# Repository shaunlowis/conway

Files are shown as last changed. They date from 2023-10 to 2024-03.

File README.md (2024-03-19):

# conway
Using my own implementation of Conway's game of life to learn more about embedded software.

# Notes to the weary traveler
- If you want to repeat this project, first order your cherry MX keys, then check the PCB layout.
  For me, the connector pins were on different locations than the schematic file I got. Update this afterwards.
- It is extremely unlikely that your LCD will have the same pinouts as mine, double check this part.
- My LCD's pins aren't in the middle of the PCB (Check the final image), if you care about this, you might want
  to adjust the location of the pins so the buttons are neatly aligned under the screen.

## Goal/Overview

- The PCB itself is supposed to just be a nice bit of desk decoration. It can all be powered
from a USB cable, connected to the STM. 
- Started out with a basic design to perpetually render Conway's game of life on an LCD
screen. Naturally scope creep ensued:
    - Made a custom PCB for mounting the screen and connecting to it.
    - Added buttons and LEDs for different rules to use.
    - Figured keyboard keys would work quite well for this. Updated PCB accordingly
- Wound up with a relatively useful shield that can be repurposed for future projects.

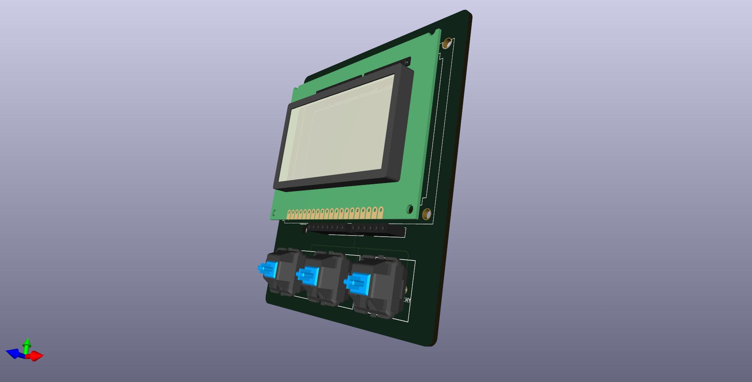
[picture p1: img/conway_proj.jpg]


First version:
<details>
<summary> Initial breadboard layout</summary>

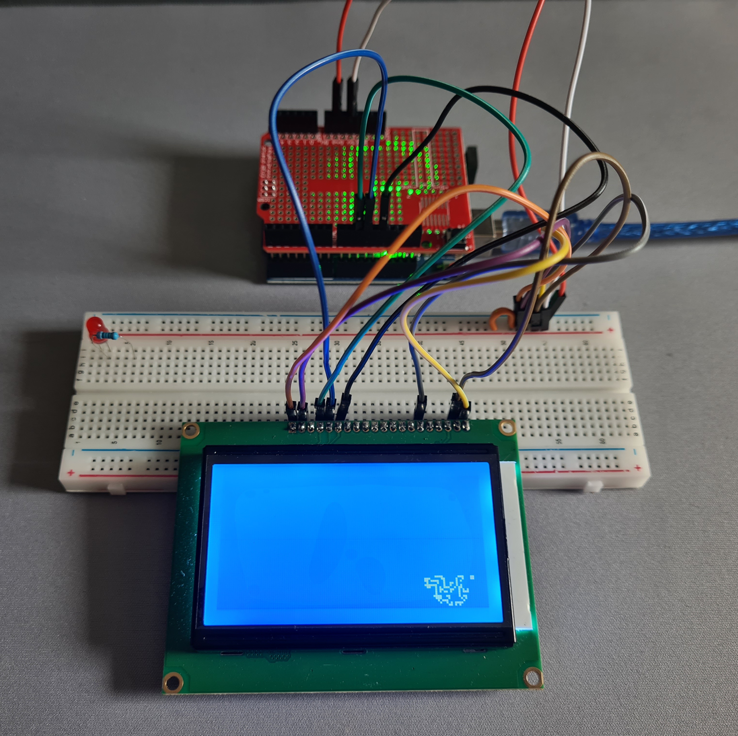
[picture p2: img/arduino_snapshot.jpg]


</details>

### Arduino support
The standard Arduino Uno does not have enough on-board memory to support a 128x64 pixel display.
In my case, pictured above, I wanted to release a version of this code that works easily for the average user.
Hence reducing the screen size to 64x36 is the largest section that we can run with a simple approach to Conway's game of life.

### Python demo
The software for Conway's game of life, for a basic python version and Arduino can be found in `/software`.

### LCD Screen config
The U8G2 Arduino library has a large amount of support for LCD screens, available [here](https://github.com/olikraus/u8g2/wiki/u8g2setupcpp). I used the `ST7920_128X64` module.

Refer to the LCD datasheet in `/circuitry` for wiring.

### STM Nucleo
On an STM32 NULCEO-F411RE, with more memory, the full 128x64 LCD screen is easily rendered.
I have made a shield that the screen can connect to directly using kicad 7. 
These files can be found under `/circuitry/kicad`. 

Install the Arduino library, then STM Core library from [here](https://github.com/stm32duino/Arduino_Core_STM32).

Great documentation on installing STM support [here](https://github.com/stm32duino/Arduino_Core_STM32/wiki/Getting-Started).

Summary of above STM install:

Install the STM Cube programmer software (required), from [here](https://www.st.com/en/development-tools/stm32cubeprog.html#get-software).
You will need to check your email for the download link to the above.

You can go to File -> Preferences -> Additional boards manager URLs, paste the link in the above documentation here.

Then click the Boards Manager icon, type "STM", then install "STM32 MCU based boards".

We can now go to "Select Board" --> Easiest to connect the STM to your PC and check its name. For me, I selected Nucleo-64.

Make sure you additionally select the correct board part number! This caught me out initially. This is in the "Tools" drop-down menu.
You can plug in your STM to your PC and open the `MBED` file, which opens a webpage with details on the model number and so-on.
If you don't have network access, your board should show up with the part number as its name as a drive in your PC.

Finally, the code uses the U8g2lib, which can be installed with: Library Manager --> search "U8g2", install first result.

<details>
<summary> First, basic layout</summary>

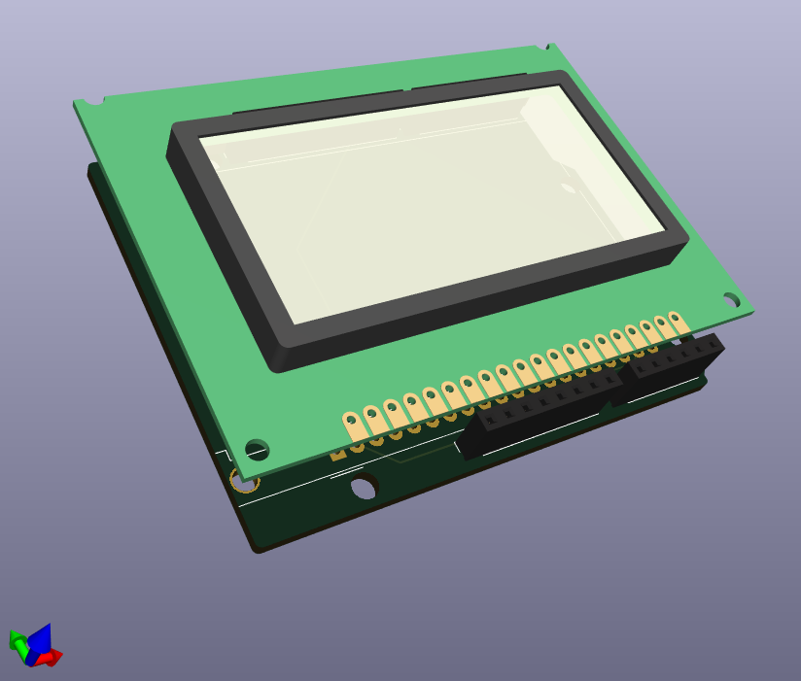
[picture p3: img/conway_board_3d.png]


Example wiring.
Barebones only display updating is in `conway_stm64.ino` for full display and a counter of generations.

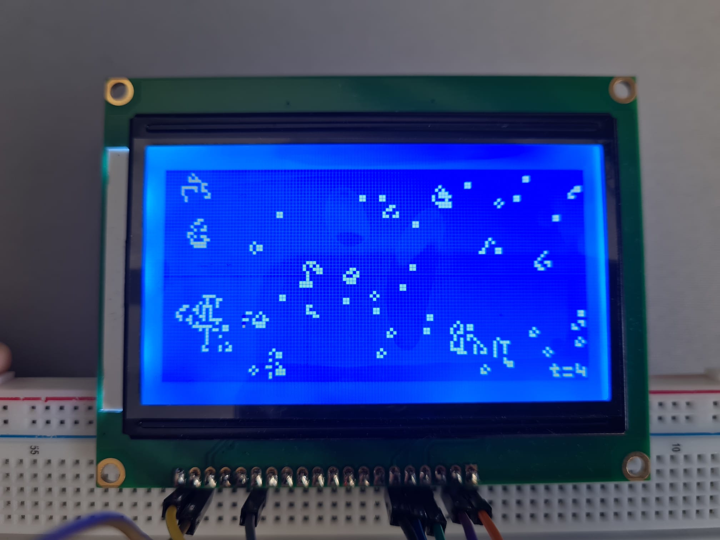
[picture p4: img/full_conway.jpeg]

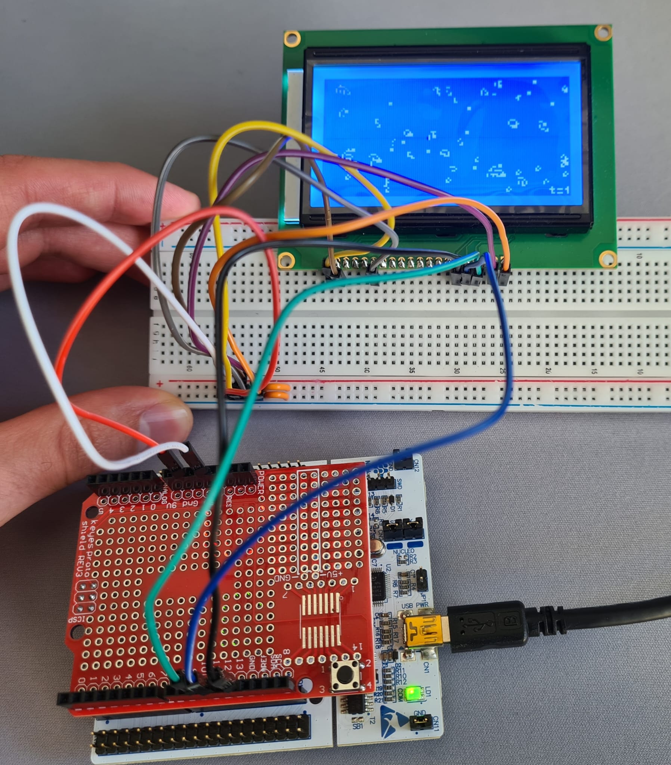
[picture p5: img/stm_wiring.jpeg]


</details>

#### Adding buttons

Additionally, buttons and LEDs were added so the user can choose different rulesets to use
for Conway's game of life. Pictured below is the "white" LED shining from selecting the
Morley's miracle rules, by clicking the white button.

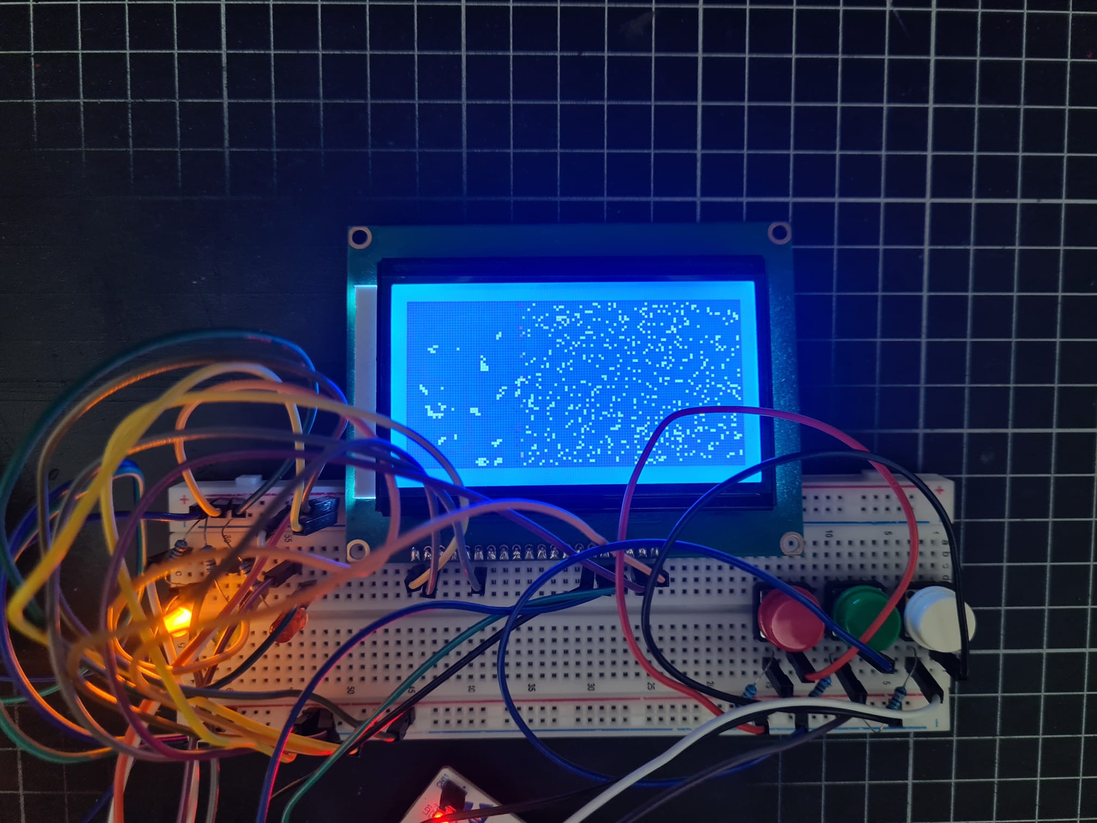
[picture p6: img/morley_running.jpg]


We now also have a more elegant PCB with support for Cherry MX keys:
I found [these](https://www.digikey.co.nz/en/products/detail/cherry-americas-llc/MX1A-E1NW/20180) 
on Digikey that had nice 3D files. This yielded the screenshot in the Overview section.

## Final PCB with screen:

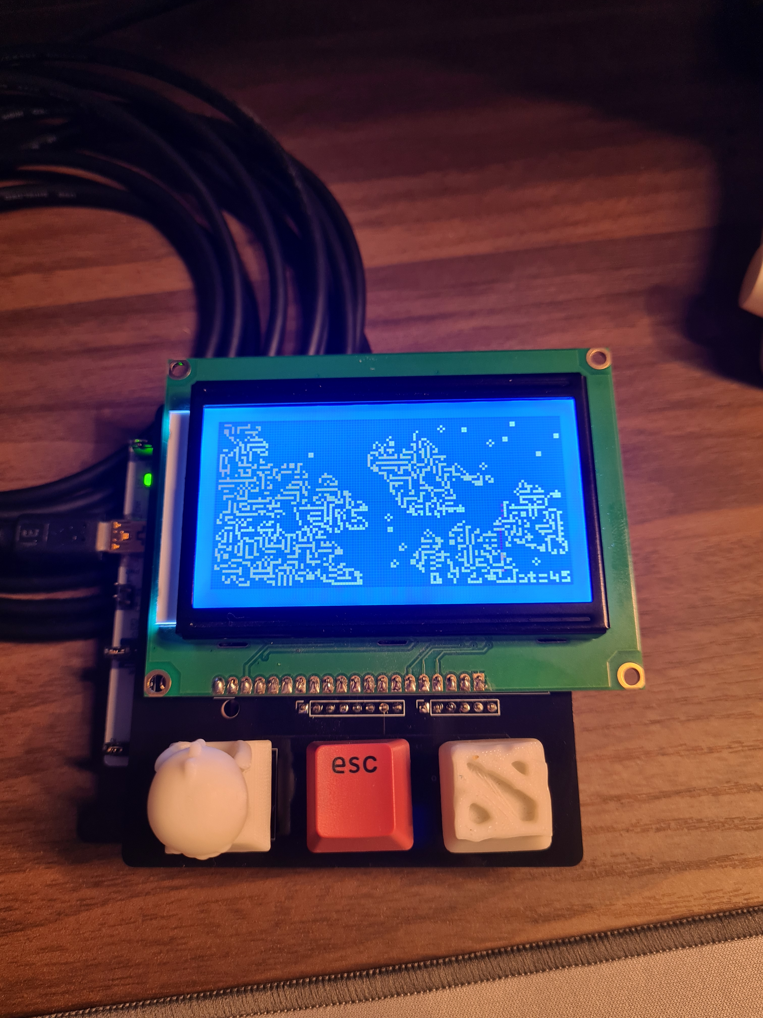
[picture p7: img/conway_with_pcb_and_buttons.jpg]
Funcitonal PCB


### TODO:
Hardware:
- Make a 3D-printed case for this, done on onshape, the .stl will be added in `/enclosure`.
- Keycaps are stupdidly expensive on Digikey, at $9 each. I should 3D print some, will also add to above folder.

Software:
- Add support for the cherry keys as they don't have resistors. See [here](https://docs.arduino.cc/tutorials/generic/digital-input-pullup/).
- Add in a button press combination to restart the simulation.
- Weird bug where pulling the power on the card fills the screen with chinese characters? Doing a reset loads graphics properly.
      - Honestly this is pretty funny so might not try to diagnose.

Reference file structure:
```
.
├── circuitry
├── enclosure
├── img
└── software
```

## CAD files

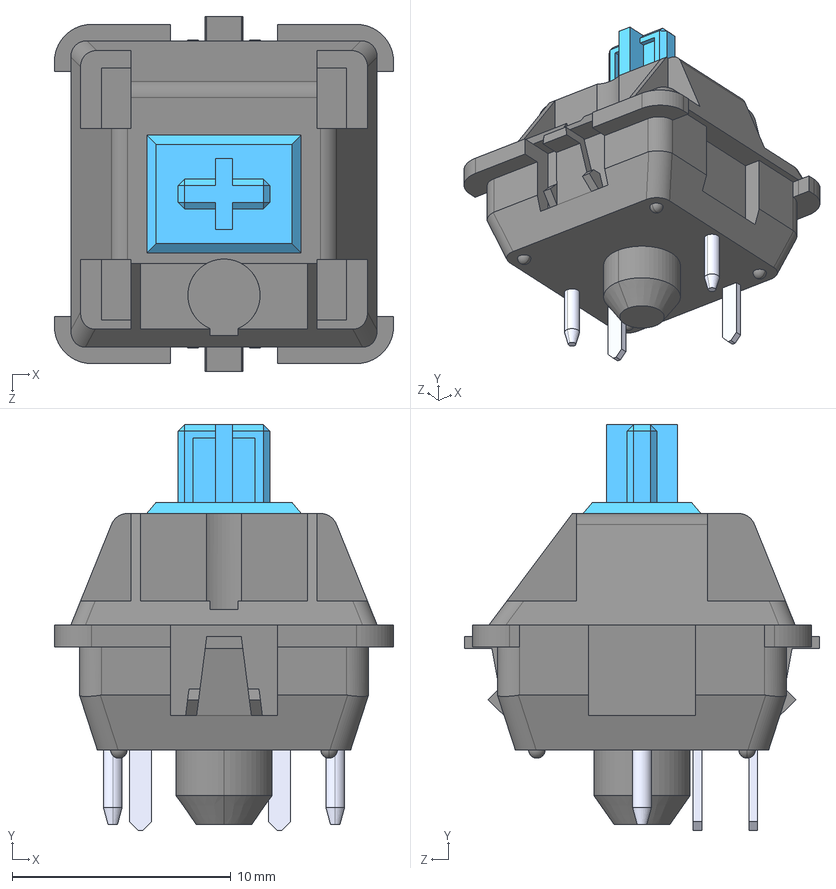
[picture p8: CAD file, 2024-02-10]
circuitry/kicad/MX1A_E1NW/KiCAD/MX1A-E1NW.STEP
15.5 x 18.5 x 16.2 mm

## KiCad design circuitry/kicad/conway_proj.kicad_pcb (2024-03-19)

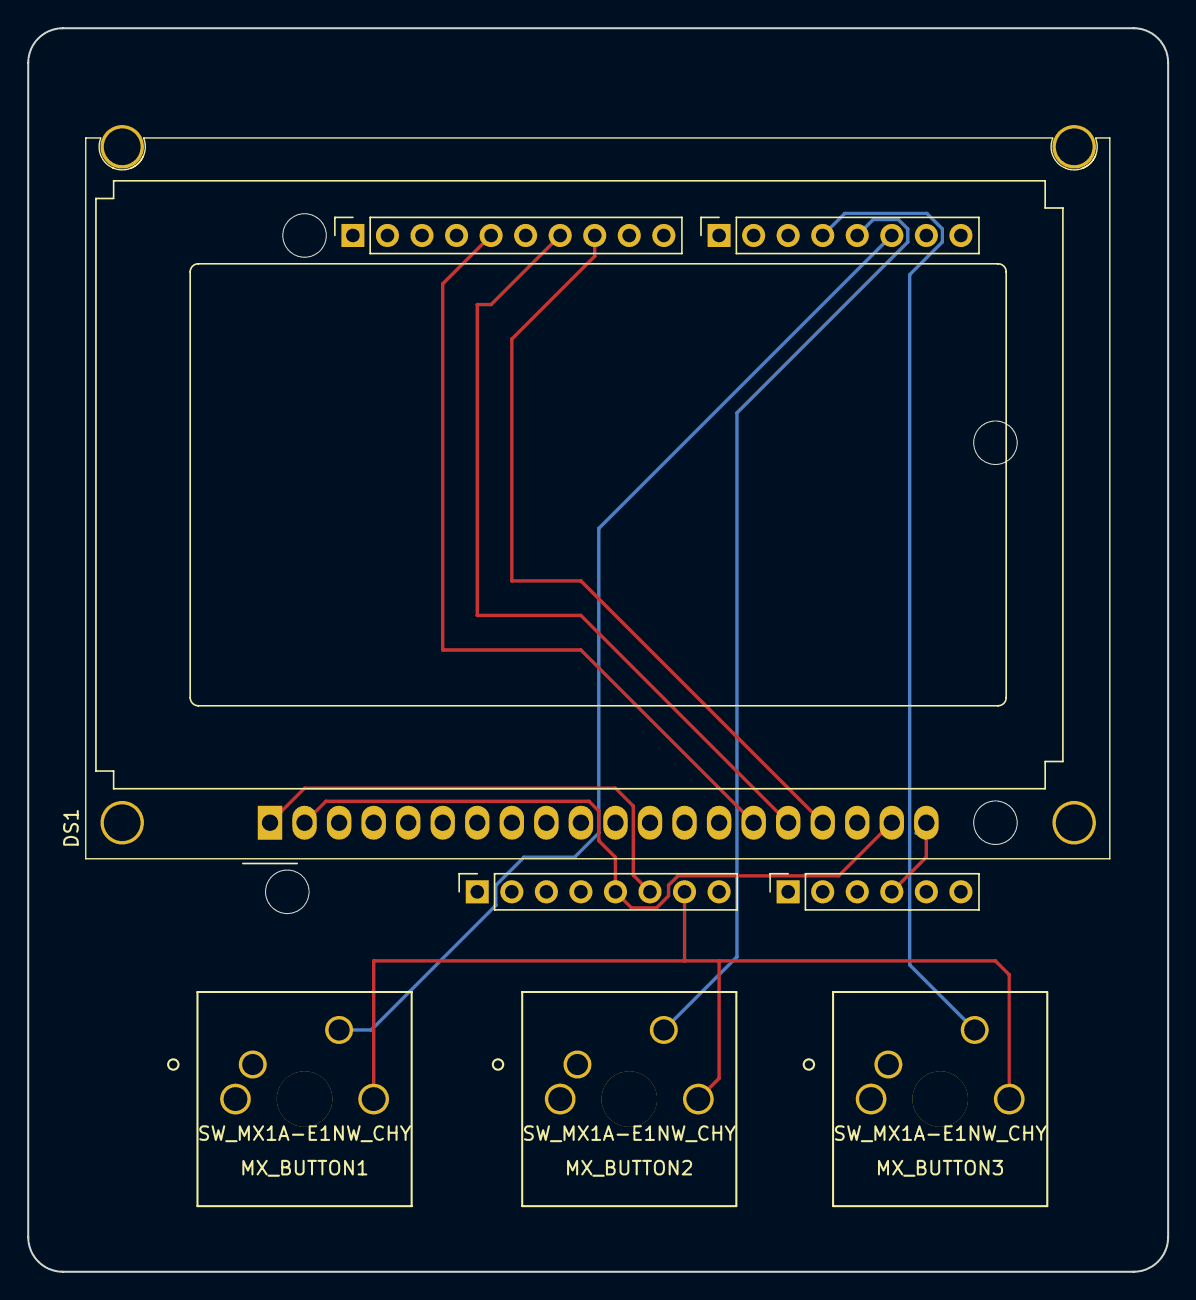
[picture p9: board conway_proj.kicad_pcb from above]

Board: 2 copper layers, 83.8 x 91.4 mm, 12 parts (0 on the bottom side), 11 nets.

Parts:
DS1: ST7920; AG12864E
J1: Power; PinSocket_1x08_P2.54mm_Vertical
J2: Digital/PWM; PinSocket_1x10_P2.54mm_Vertical
J3: Analog; PinSocket_1x06_P2.54mm_Vertical
J4: Digital/PWM; PinSocket_1x08_P2.54mm_Vertical
MH1, MH2, MH3, MH4: MountingHole_3.2mm
MX_BUTTON1, MX_BUTTON2, MX_BUTTON3: SW_MX1A-E1NW_CHY; MX1A-E1NW

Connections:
+5V: DS1.2 (GND), DS1.19 (LEDA/EL), J1.5
/2: J4.6, MX_BUTTON1.2
/4: J4.4, MX_BUTTON3.2
/13: DS1.15 (R/~W), J2.5
/*3: J4.5, MX_BUTTON2.2
/*10: DS1.17 (E), J2.8
/*11: DS1.16 (D/~I), J2.7
/SCL/A5: J2.1, J3.6
/SDA/A4: J2.2, J3.5
/passive: DS1.3 (VO), DS1.4 (DB0), DS1.5 (DB1), DS1.7 (DB3), DS1.8 (DB4), DS1.9 (DB5), DS1.10 (DB6), DS1.11 (DB7), DS1.12 (~CS1), DS1.13 (~CS2), DS1.14 (~RST), DS1.18 (VEE)
GND: DS1.1 (VCC), DS1.6 (DB2), DS1.20 (LEDK/EL), J1.6, J1.7, J2.4, J3.4, MX_BUTTON1.5, MX_BUTTON2.5, MX_BUTTON3.5

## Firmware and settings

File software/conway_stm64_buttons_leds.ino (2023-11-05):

/*
  Writing Conway's game of life for a microcontroller.
  This file requires the U8g2lib library.
  Code by Shaun Lowis.
  This version includes setting custom rules and support for
  buttons and LEDs to indicate active rules.
*/

#include <Arduino.h>
#include <U8g2lib.h>

#ifdef U8X8_HAVE_HW_SPI
#include <SPI.h>
#endif
#ifdef U8X8_HAVE_HW_I2C
#include <Wire.h>
#endif

/*
  Screen & time configuration, I use a boolean array to keep track of cell states.
  Here, true = alive, false = dead. The timesteps var tracks simulation runtime.
*/

U8G2_ST7920_128X64_F_SW_SPI u8g2(U8G2_R0, /* clock=*/ 13, /* data=*/ 11, /* CS=*/ 10, /* reset=*/ 8);
bool screen[128][64];
int timesteps = 1; // Start at 1 since zero is the initial random grid.

/*
  Initialise button and LED states. Digital pin mapping:
  Colours are simply how I've debugged the initial setup on the breadboard and 
  may not present in the final config. I am well aware that this limits the types of rules I can have.
  I am not interested in adding a ton of different rules as simplicity is elegance :^)

  Green button : pin 0
  White button : pin 1
  Red button   : pin 2

  Green LED    : pin 6
  White LED    : pin 7
  Red LED      : pin 5
*/

// Map the button and LED to the appropriate pins
const int green_button_pin = 2; 
const int green_led_pin = 6;
// Set their initial states, LEDs start powered off.
// Buttons are considered active when pressed.
int green_led_state = HIGH;
int green_button_state;
int last_green_button_state = LOW;

// Repeat for other buttons and LEDs
const int white_button_pin = 3; 
const int white_led_pin = 5;
int white_led_state = HIGH;
int white_button_state;
int last_white_button_state = LOW;

const int red_button_pin = 4; 
const int red_led_pin = 7;
int red_led_state = HIGH;
int red_button_state;
int last_red_button_state = LOW;

// Used to check if the button was toggled.
unsigned long green_debounce_time = 0;  
unsigned long red_debounce_time = 0;
unsigned long white_debounce_time = 0;
unsigned long debounceDelay = 250;    // the debounce time; increase if the output flickers

// Define menu options
enum menu_option {
  DEFAULT_RULES, // green button, LED
  HIGHLIFE, // red button, LED
  MORLEY, // white button, LED
};

// Select a default to assign to selected_option
menu_option selected_option = DEFAULT_RULES;

// Trigger the menu and initial grid functions in loop()
bool menu_displayed = true;
bool draw_initial_grid = true;

void handle_menu() {
  // Display menu options on the LCD
  u8g2.clearBuffer();
  u8g2.setFont(u8g2_font_u8glib_4_tf);
  u8g2.drawStr(1, 15, "Select a rule, via a [coloured] button:");
  u8g2.drawStr(15, 30, "Default Conway's [green]");
  u8g2.drawStr(15, 40, "Highlife [red]");
  u8g2.drawStr(15, 50, "Morley's Miracle [white]");
  u8g2.sendBuffer();

  while (menu_displayed){
    // ------------------ Control logic, see examples/Debounce.ino: --------------------- //
    // Here I just repeat it for the respective colours and update the game state accordingly.

    // If the switch changed, due to noise or pressing:
    int green_reading = digitalRead(green_button_pin);
    if (green_reading != last_green_button_state) {
      // reset the debouncing timer
      green_debounce_time = millis();
    }
    if ((millis() - green_debounce_time) > debounceDelay) {
      // whatever the reading is at, it's been there for longer than the debounce
      // delay, so take it as the actual current state:

      // if the button state has changed:
      if (green_reading != green_button_state) {
        green_button_state = green_reading;
        // only toggle the LED if the new button state is HIGH
        if (green_button_state == HIGH) {
          // Update Conway rules:
          selected_option = DEFAULT_RULES;
          // set the LED:
          digitalWrite(green_led_pin, !green_led_state);
          menu_displayed = false; // want to exit the loop if a button is pressed.
          u8g2.clearBuffer();
          u8g2.drawStr(10, 32, "Selected default rules [green]");
          u8g2.sendBuffer();
          delay(2000);
        }
      }
    }
    // save the reading. Next time through the loop, it'll be the lastButtonState:
    last_green_button_state = green_reading;

    // ----------------------------------- WHITE LED ----------------------------------- //
    int white_reading = digitalRead(white_button_pin);
    if (white_reading != last_white_button_state) {
      white_debounce_time = millis();
    }
    if ((millis() - white_debounce_time) > debounceDelay) {
      if (white_reading != white_button_state) {
        white_button_state = white_reading;
        if (white_button_state == HIGH) {
          selected_option = MORLEY;
          digitalWrite(white_led_pin, !white_led_state);
          menu_displayed = false;
          u8g2.clearBuffer();
          u8g2.drawStr(10, 32, "Selected Morley's Miracle [white]");
          u8g2.sendBuffer();
          delay(2000);
        }
      }
    }
    last_white_button_state = white_reading;

    // ----------------------------------- RED LED ----------------------------------- //
    int red_reading = digitalRead(red_button_pin);
    if (red_reading != last_red_button_state) {
      red_debounce_time = millis();
    }
    if ((millis() - red_debounce_time) > debounceDelay) {
      if (red_reading != red_button_state) {
        red_button_state = red_reading;
        if (red_button_state == HIGH) {
          selected_option = HIGHLIFE;
          digitalWrite(red_led_pin, !red_led_state);
          menu_displayed = false;
          u8g2.clearBuffer();
          u8g2.drawStr(10, 32, "Selected Highlife [red]");
          u8g2.sendBuffer();
          delay(2000);
        }
      }
    }
    last_red_button_state = red_reading;
  }
}


void draw_start_screen(){
  // Clear the screen:
  u8g2.clearBuffer();

  // Generate some random points at the start of every game.
  // This is inside of the outer edge, same as my iteration.
  for (int rand_starts = 0; rand_starts < 1000; rand_starts++){
    int rand_x = random(1, 127);
    int rand_y = random(1, 63);
    u8g2.drawBox(rand_x, rand_y, 1, 1);
    screen[rand_x][rand_y] = true;
  }

  u8g2.sendBuffer();
  draw_initial_grid = false; // We only want this function called once.
}


bool apply_rules(bool cell, int selected_option, int total){
  // Based off the initial menu selection, apply some different rules.
  if (selected_option == DEFAULT_RULES){
    // Defining Conway's rules:
    // Rule 1: A live cell dies if it has fewer than two live neighbors.
    if (cell && total < 2) {
      cell = false;
    }
    // Rule 2: A live cell with more than three live neighbors dies.
    else if (cell && total > 3) {
      cell = false;
    }
    // Rule 3: A live cell with two or three live neighbors lives on to the next generation.
    else if (cell && (total == 2 || total == 3)) {
      cell = true;
    }
    // Rule 4: A dead cell will be brought back to live if it has exactly three live neighbors.
    else if (cell == false && total == 3) {
      cell = true;
    }
  }

  else if (selected_option == HIGHLIFE){
    // Uses B36/S23 rules, this notation refers to birth and survival rules.
    //  - B36 means a cell is born if it has 3 or 6 neighbours.
    //  - S23 means a cell survives if it has 2 or 3 neighbours.
    if (cell && (total == 2 || total == 3)){
      cell = true;
    }
    else if (cell == false && (total == 3 || total == 6)){
      cell = true;
    }
    else {
      cell = false;
    }
  }

  else if (selected_option == MORLEY){
    // Uses B368/S245 rules, this notation refers to birth and survival rules.
    //  - B368 means a cell is born if it has 3 or 6 or 8 neighbours.
    //  - S23 means a cell survives if it has 2 or 4 or 5 neighbours.
    if (cell && (total == 2 || total == 4 || total == 5)){
      cell = true;
    }
    else if (cell == false && (total == 3 || total == 6 || total == 8)){
      cell = true;
    }
    else {
      cell = false;
    }
  }

  return cell;
}


void setup(void) {
  u8g2.begin();
  // Set a nice font for timestep updating.
  u8g2.setFont(u8g2_font_u8glib_4_tf);
  u8g2.clearBuffer();	

  // Set up button pins as inputs, LEDs as outputs
  pinMode(green_button_pin, INPUT);
  pinMode(green_led_pin, OUTPUT);

  pinMode(white_button_pin, INPUT);
  pinMode(white_led_pin, OUTPUT);

  pinMode(red_button_pin, INPUT);
  pinMode(red_led_pin, OUTPUT);

  // Set the LEDs to be off initially.
  digitalWrite(green_led_pin, green_led_state);
  digitalWrite(white_led_pin, white_led_state);
  digitalWrite(red_led_pin, red_led_state);
}

void loop(void) {
  // This calls the handle_menu() function once and waits until a user selects
  // the appropriate start condition.
  if (menu_displayed){
    handle_menu();
    }

  // After the menu is finished, create the starter grid once.
  if (draw_initial_grid){
    draw_start_screen();
    }

  for (int i = 1; i < 127; i++) {
    for (int j = 1; j < 63; j++) {
      int total = 0;

      if(screen[i - 1][j + 1]){ // top_left_val
        total += 1;
      }
      if(screen[i][j + 1]){ // top_val
        total += 1;
      }
      if(screen[i + 1][j + 1]){ // top_right_val
        total += 1;
      }
      if(screen[i + 1][j]){ // right_val
        total += 1;
      }
      if(screen[i + 1][j - 1]){ // bottom_right_val
        total += 1;
      }
      if(screen[i][j - 1]){ // bottom_val
        total += 1;
      }
      if(screen[i - 1][j - 1]){ // bottom_left_val
        total += 1;
      }
      if(screen[i - 1][j]){ // left_val
        total += 1;
      }

      // Calling this as a function lets us vary the rules for the game, from user input.
      screen[i][j] = apply_rules(screen[i][j], selected_option, total);
      
      // Draw a pixel if the corresponding 'screen' array value is true
      // I prefer this method of updating for visual appeal
      if (screen[i][j]){
        u8g2.setDrawColor(1);
        u8g2.drawPixel(i, j); 
      }
      else {
        u8g2.setDrawColor(0);
        u8g2.drawPixel(i, j);
      }
    }
    u8g2.sendBuffer();
  }

  // Display a counter of how many timesteps the simulation has been running for.
  char formattedString[20];
  sprintf(formattedString, "t=%d", timesteps);

  int fontX = (127 - u8g2.getStrWidth(formattedString));
  int fontY = 63; // Using the 3 pixel height font

  u8g2.setDrawColor(1);
  u8g2.drawStr(fontX, fontY, formattedString);
  u8g2.sendBuffer();

  timesteps += 1;
}

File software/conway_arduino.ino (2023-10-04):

/*
Writing Conway's game of life for a microcontroller.
This file requires the U8g2lib library.
Code by Shaun Lowis.
*/
#include <Arduino.h>
#include <U8g2lib.h>

#ifdef U8X8_HAVE_HW_SPI
#include <SPI.h>
#endif
#ifdef U8X8_HAVE_HW_I2C
#include <Wire.h>
#endif

/*
  U8g2lib Example Overview:
    Frame Buffer Examples: More RAM intensive, but can get values back from array.
    Page Buffer Examples: Can't use this method as we need to get cell values back from our display.
    U8x8 Text Only Example: No RAM usage, direct communication with display controller. No graphics, 8x8 Text only.
    
*/

U8G2_ST7920_128X64_F_SW_SPI u8g2(U8G2_R0, /* clock=*/ 13, /* data=*/ 11, /* CS=*/ 10, /* reset=*/ 8);
// U8G2_ST7920_128X64_1_SW_SPI u8g2(U8G2_R0, /* clock=*/ 13, /* data=*/ 11, /* CS=*/ 10, /* reset=*/ 8);

// bool screen[128][64];
bool screen[32][16];

void setup(void) {
  u8g2.begin();
  // Start conditions for Conway, draw some initial points manually.
  // The screen dimensions are 128 x 64
  
  u8g2.clearBuffer();	

  // Make a glider near the middle ish of the screen.
  // Draw the values
  u8g2.drawBox(56, 30, 1, 1);
  u8g2.drawBox(57, 30, 1, 1);
  u8g2.drawBox(58, 30, 1, 1);
  u8g2.drawBox(56, 31, 1, 1);
  u8g2.drawBox(57, 32, 1, 1);

  // Update the screen array.
  screen[56][30] = true;
  screen[57][30] = true;
  screen[58][30] = true;
  screen[56][31] = true;
  screen[57][32] = true;

  // Generate some random points at the start of every game.
  // This is inside of the outer edge, same as my iteration.
  for (int rand_starts = 0; rand_starts < 100; rand_starts++){
    // int rand_x = random(1, 127);
    // int rand_y = random(1, 63);
    int rand_x = random(1, 31);
    int rand_y = random(1, 15);
    u8g2.drawBox(rand_x, rand_y, 1, 1);
    screen[rand_x][rand_y] = true;
  }

  u8g2.sendBuffer();
}

void loop(void) {
  // Now that we have our screen defined, we can clear the display.
  u8g2.clearBuffer();	

  for (int i = 1; i < 31; i++) {
    for (int j = 1; j < 15; j++) {
      int total = 0;

      if(screen[i - 1][j + 1]){ // top_left_val
        total += 1;
      }
      if(screen[i][j + 1]){ // top_val
        total += 1;
      }
      if(screen[i + 1][j + 1]){ // top_right_val
        total += 1;
      }
      if(screen[i + 1][j]){ // right_val
        total += 1;
      }
      if(screen[i + 1][j - 1]){ // bottom_right_val
        total += 1;
      }
      if(screen[i][j - 1]){ // bottom_val
        total += 1;
      }
      if(screen[i - 1][j - 1]){ // bottom_left_val
        total += 1;
      }
      if(screen[i - 1][j]){ // left_val
        total += 1;
      }

      // Defining Conway's rules:
      // Rule 1: A live cell dies if it has fewer than two live neighbors.
      if (screen[i][j] && total < 2) {
        screen[i][j] = false;
      }
      // Rule 2: A live cell with more than three live neighbors dies.
      else if (screen[i][j] && total > 3) {
        screen[i][j] = false;
      }
      // Rule 3: A live cell with two or three live neighbors lives on to the next generation.
      else if (screen[i][j] && (total == 2 || total == 3)) {
        screen[i][j] = true;
      }
      // Rule 4: A dead cell will be brought back to live if it has exactly three live neighbors.
      else if (screen[i][j] == false && total == 3) {
        screen[i][j] = true;
      }
      
      if (screen[i][j]){
        u8g2.drawPixel(i, j); // Draw a pixel if the corresponding 'screen' array value is true
      }
    }
    u8g2.sendBuffer();
  }
  delay(1000);
}

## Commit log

2023-10-18 hopefully finished circuitry
    [conway_proj-B_Cu.gbr, conway_proj-B_Mask.gbr, conway_proj-B_Paste.gbr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]
2023-10-18 Generated step file for making enclosure.
2023-11-05 Create conway_stm64_buttons_leds.ino
    This version adds support for buttons, LEDs and different rulesets.
2023-11-05 Create debug_buttons_leds.ino
    This was useful to see if the wiring and so on of my breadboard was correct.
    [debug_buttons_leds.ino]
2024-02-10 New KiCad version and README updates
    [MX1A-E1NW.STEP, conway_proj.kicad_pcb]
2024-02-10 Included new gerber files and updated layout
    [conway_proj-B_Cu.gbr, conway_proj-B_Mask.gbr, conway_proj-B_Paste.gbr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]
2024-03-19 Updated PCB layout, fixed 5V and ground to LCD connections.
    [conway_proj.kicad_pcb]

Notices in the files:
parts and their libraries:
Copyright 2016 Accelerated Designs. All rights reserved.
